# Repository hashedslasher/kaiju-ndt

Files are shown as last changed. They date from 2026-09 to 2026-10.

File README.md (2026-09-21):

# Kaiju U-NDT

This is my team's EE senior design project. It is in very early development and will evolve into an autonomous immersion UT device.
The [pic0rick](https://github.com/kelu124/pic0rick) is used for the pulser/receiver, and the V1 Engineering [MPCNC](https://docs.v1e.com/mpcnc/intro) will be used for xyz gantry

The name Kaiju came from a toy that randomly appeared in our lab one day

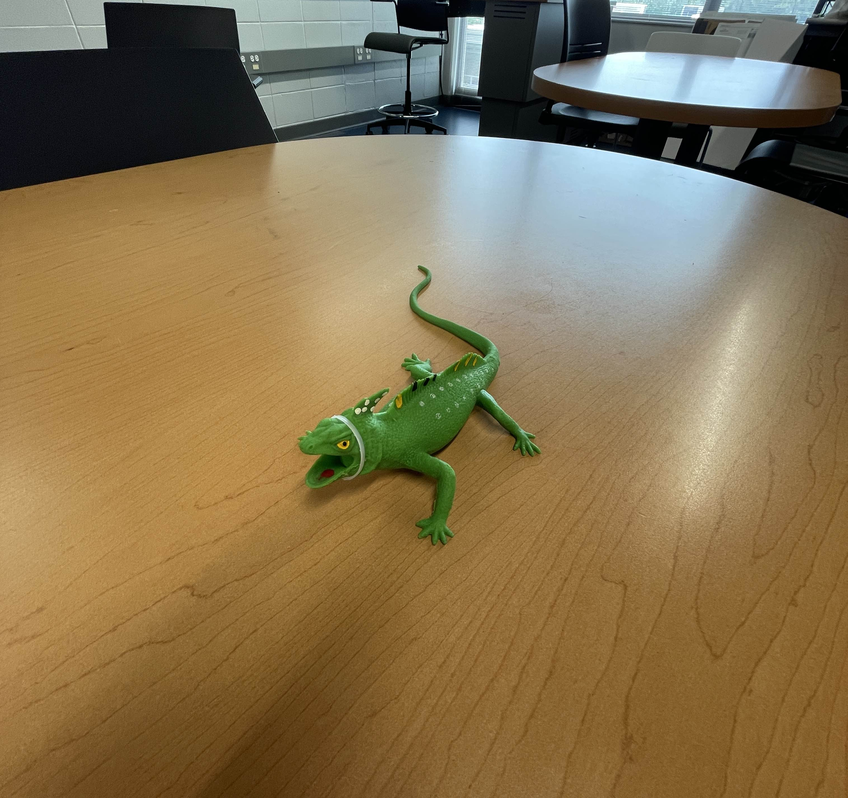
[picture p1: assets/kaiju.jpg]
Kaiju toy


## Development
   If you are working on this project see [Setup](setup/README.md)

## To run the python scripts

1. **Clone the repo**
   Clone the repo (or download as zip) and cd into kaiju-ndt.

2. **Install Python and dependencies**
   - **Windows:** Download from [python.org](https://www.python.org/downloads/windows/) or run:
     ```bash
     winget install -e --id python.python.3.14
     ```
   - **MacOS:** Download from [python.org](https://www.python.org/downloads/macos/) or run:
     ```bash
     brew install python3
     ```
   - **Linux:** Install python with your package manager:
   
   Debian based:
   ```bash
   sudo apt install python3 python3-pip
   ```
   Arch:
   ```bash
   sudo pacman -S python python-pip
   ```
### Python dependencies
   - Open PowerShell or Terminal and run:
     ```bash
     pip install -r python-tools/requirements.txt
     ```

3. **Flashing the firmware**
   - If the firmware isn't already on the pico, you need to flash it.
   - Hold `BOOTSEL` and plug the board in. It should appear as `RPI-RP2`.
   - Drag and drop `firmware/pico/rp2040.uf2` (Pico) or `firmware/pico/rp2350.uf2` (Pico 2) into the `RPI-RP2` drive.
   - Or with picotool from the root of the repository:
   ```bash
   picotool load firmware/pico/rp2040.uf2
   ```

4. **Run a script**
   In PowerShell or Terminal:
   ```bash
   python3 python-tools/{script_name}.py
   ```

   If you use nix for some reason just:
   ```bash
   nix develop .
   python3 python-tools/{script_name}.py
   ```

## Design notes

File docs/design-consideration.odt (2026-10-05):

Design Considerations

Initial Design Considerations

Create an Ultrasonic Testing instrument.

Constraint 1 – Budget

Team agreed to spend $80 per student. 5 students in our team: 5 * $80 = $400.

Team budget: ~$400

Design consideration modified - 1

Create an affordable Ultrasonic Testing instrument based on a pre existing AFE.

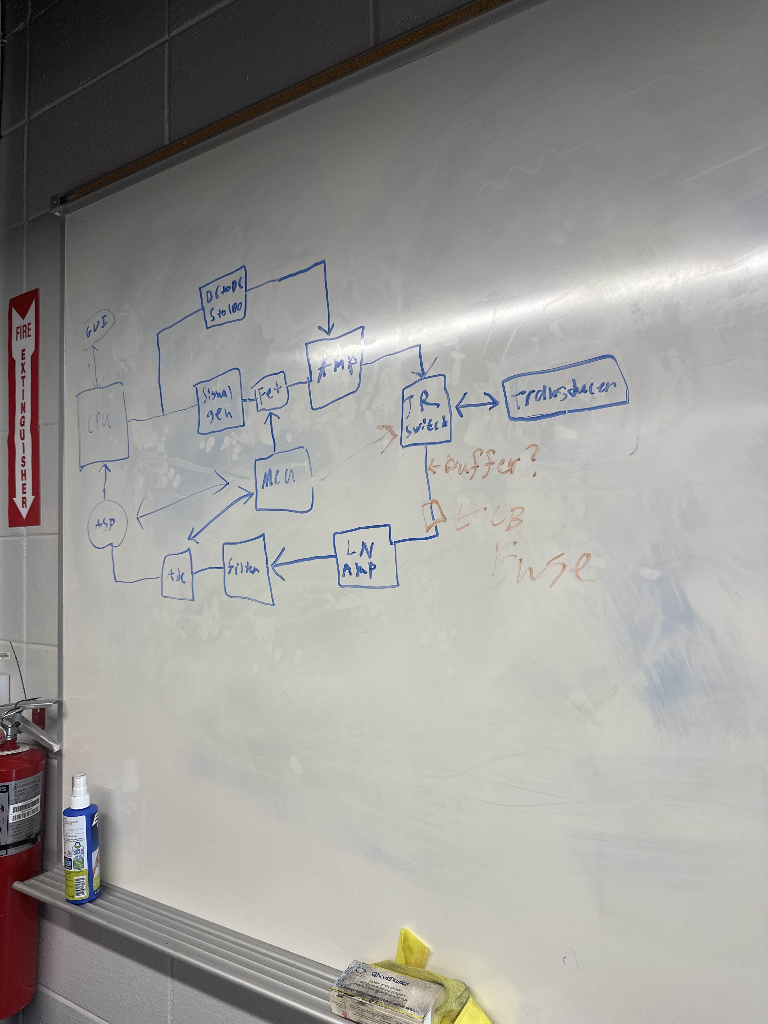
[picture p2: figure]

Basic block diagram of a pulse-echo system using tone burst (Layton).

Visted Marietta NDT. Advised to use an existing instrument and work at the system level. Potentially receiving an immersion probe.

Design consideration modified – 2 (Final)

Affordable Autonomous immersion defect detection system capable of producing C-scans.

Instrument Investigation

Discovered Echomods project: Family of open-source ultrasound pulser/reciever boards - (Layton)

Instruments considered (technically, these are pulser/reciever boards):

Board | Capabilities
lit3-32 | Capable of 100V 3 line pwm pulses. Controlled by FPGA (iCE40). 92dB gain VGA
un0rick | Capable of 25V, 50V, or 75V pwm pulses. Controlled by FPGA (iCE40). 48dB VGA
pic0rick | Capable of +-25V 3 line pwm pulses. Controlled by RP2040/RP2350. 48dB VGA

lit3-32 and un0rick are legacy and no longer produced. Pic0rick is the only modern option in it’s class and price range.

Due to the entire echomods project being open-source, printing the lit3-32 was strongly considered but advised against by senior project professor.

Pic0rick and lit3-32 were around the same price. After considering common probe specs, Pic0rick can achieve desired results, but overhead of lit3-32 and FPGA flexabilty would provide better results.

Pic0rick was selected with raspberry pi pico as MCU - (Layton).

Budget Update

Board and acessories (headers, sma connectors, sma cables, pico) totaled to ~$400. Board and accessories were purchased with financial assistance from senior project professor.

New team buget: $400 + $400 - $400 = $400

Design Constraint - 2

Raspberry pi pico uses USB 1.1, theoretically 12Mbps, practically much lower.

Design Constraint - 3

Pic0rick board leaves 8 remaining gpio pins. Need to eventually drive motors (limit switches, E-stop, temp sensors).

Initial Testing

Main board (reciever) and daughter board (pulser) arrived. Headers and Raspberry pi pico 1 were installed (Harrison). Board was hooked up to 10Mhz delay-line contact probe provided by senior project professor. Extremely minimal firmware gave a completely raw, one-pulse signal with no DSP. Pulse was called with simple python function through live python environment with computer connected to board via serial (usb).

Signal filtering was then applied (through interface) via bandpass filter, averaging, and hilbert envelop and displayed with pyqt. Target was a blank slab of steel with no known defects. Patroleum jelly was used as couplant.

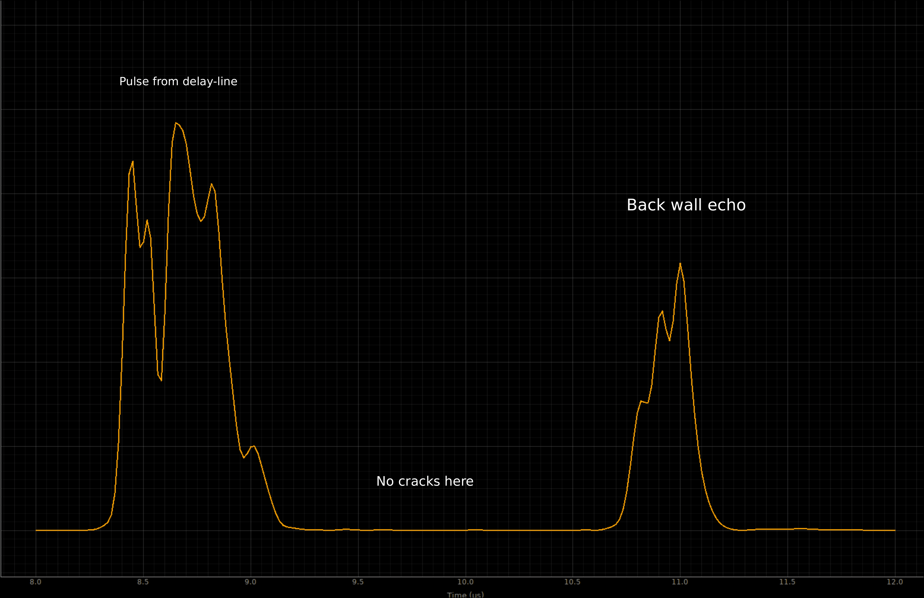
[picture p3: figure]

Python script was implemented to loop python function that triggers pulse and acquisition, along with windowing feature, input for gain, etc. (Mathew). Acquisition rate was approximately 1 pulse per 2 seconds.

Firmware was overhauled to use fast_pico_serial (Layton). Acquisition rate jumped to approximately 30 pulses per second with above signal processing and 2 signal averages.

Motion System Considerations

Used 3D printers and frugal CNC machines were considered for xyz motion system. Most 3D printers at a reasonable price move bed for y movement. This is not acceptable as water in scan area is sloshed. Both consumer/commercial CNC machines and 3D printers use dedicated microcontrollers with propriatary, unmodifiable firmware.

The MPCNC (Mostly Printable CNC) was discovered – (Layton)

The MPCNC is a guide to build a CNC machine with 3D printed parts and items found at local hardware stores and movement is driven by user choice of 5 Nema-17 motors. The user is required to choose microcontroller and motor drivers.

MPCNC was selected – (Layton)

Original MPCNC qoute for user sourcing parts was ~$450 (including cnc router, which isn’t used here)

MPCNC parts were reviewed for practicality and printed (Layton, Harrison, Matthew)

MPCNC was successfully assembled (Mathew) for ~$280

MCU Considerations

To get a usable scan resolution, micro controller needs to either support much higher serial transfer rate, or allow for onboard dsp to shrink size of data sent over serial.

Motors can be driven by the 8 remaining gpio pins due to 2 x axis motors rotating in opposing direction and 2 y axis motors rotating in opposing direction. This leaves no room for limit switches, E-stop, etc.

Solution | Pros | cons
PCB with motor controllers built around teensy 4.0. M/s setup between teensy and pico 1 | 3.0 USB speeds. Heavier onboard DSP. more gpio | Cost of teensy 4.0. M/s complexity. 2 sets of firmware
Move pic0rick to pico 2. Build gpio extension/motor driver drop in PCB | Onboard DSP with arm_math (none on pico 1). $2 increase in MCU cost. | Still limited to usb 1.1. added complexity of gpio expansion PCB

Replace pico 1 with pico 2 on pic0rick. Build gpio expansion pcb - (Layton)

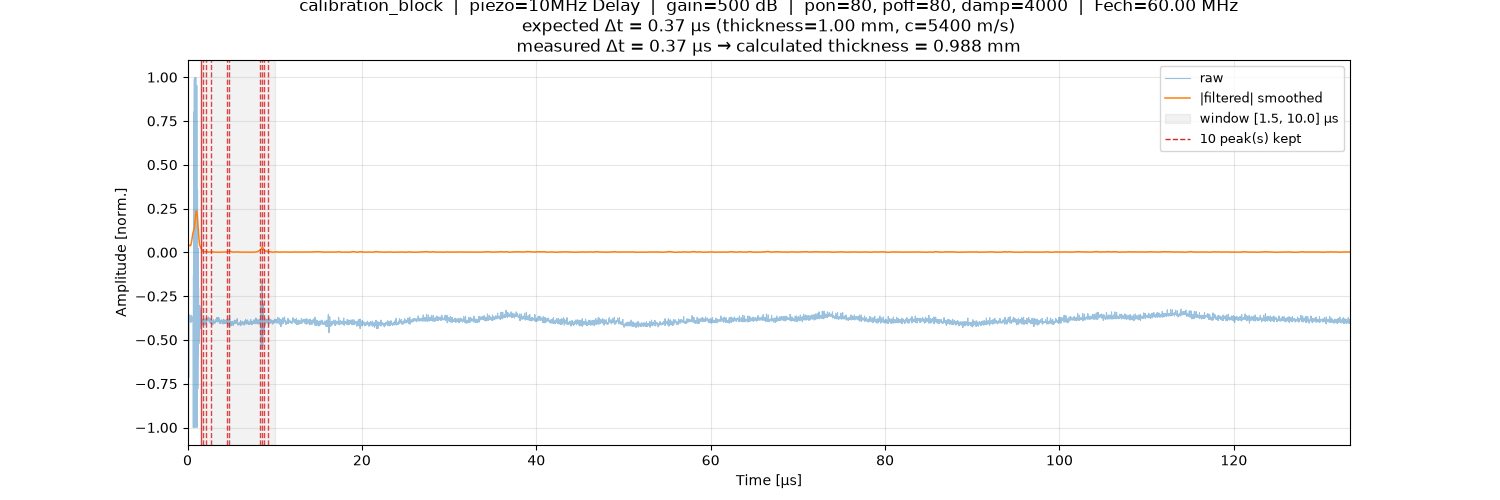
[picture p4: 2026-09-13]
plots/9-4-26/plot_20260904_140533.png

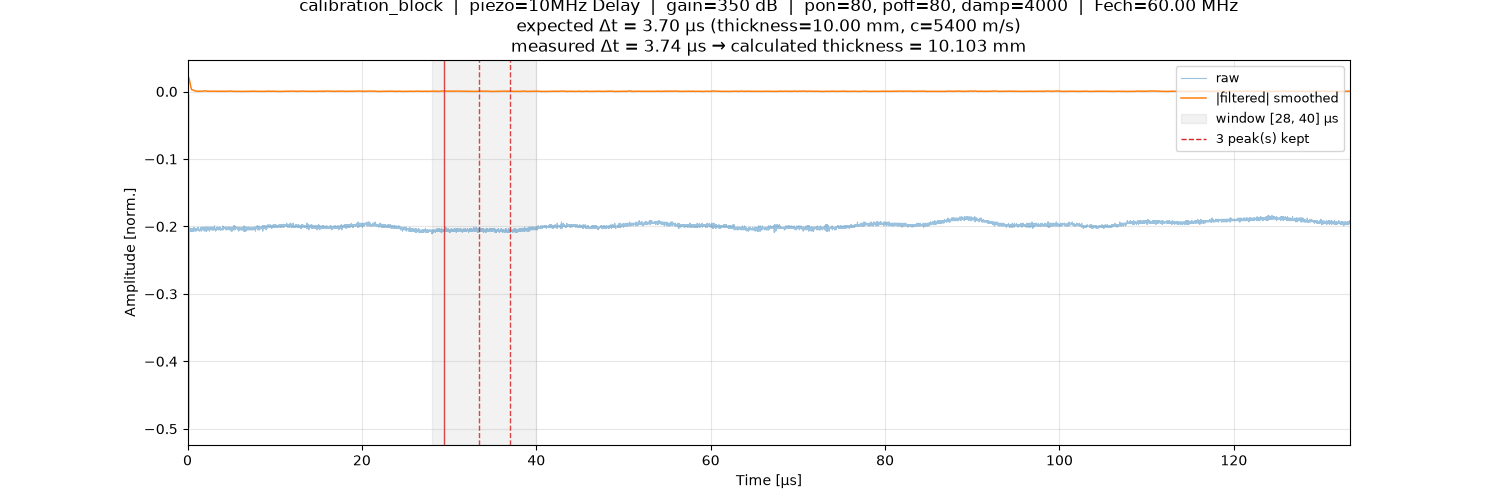
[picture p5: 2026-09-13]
plots/9-4-26/plot_20260904_145508.png

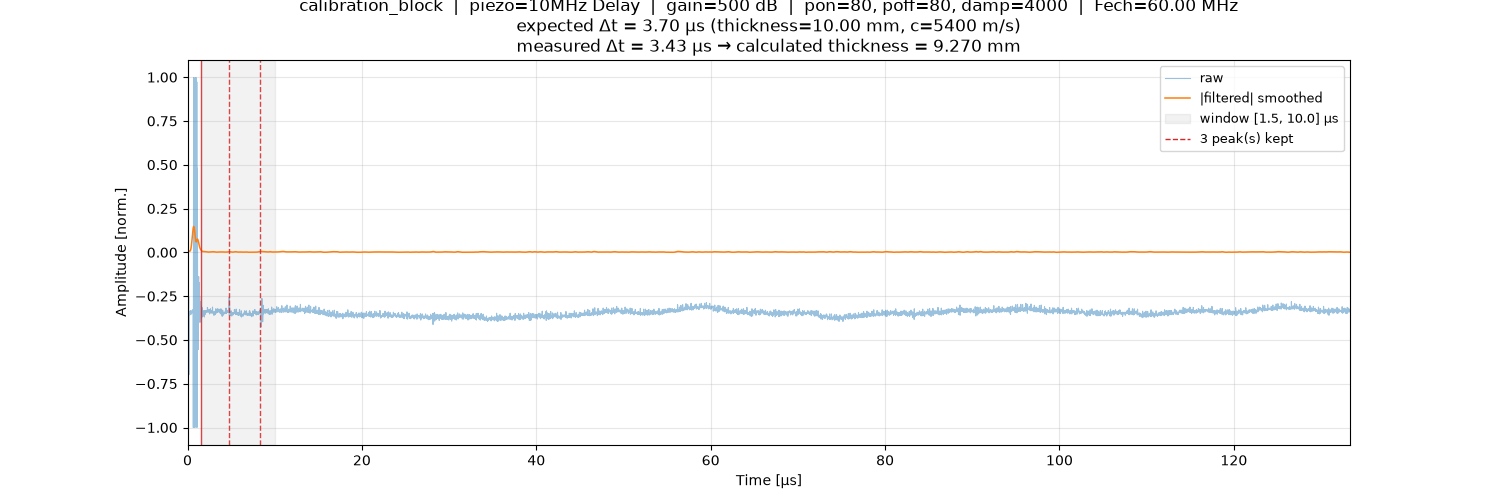
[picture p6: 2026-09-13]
plots/9-4-26/plot_20260904_141416.png

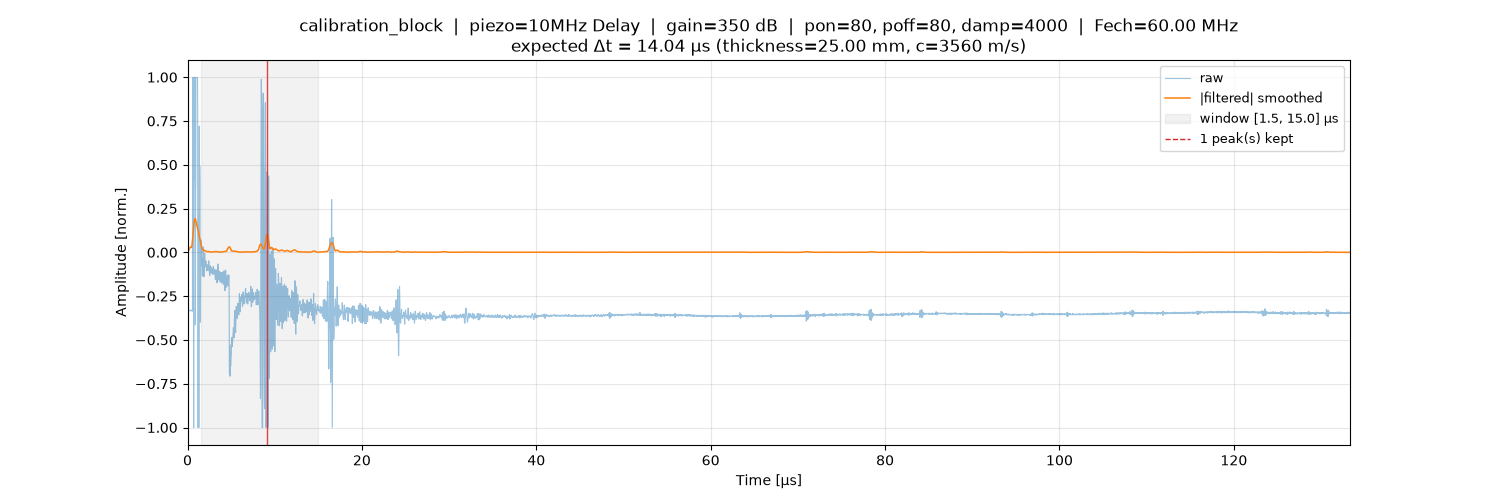
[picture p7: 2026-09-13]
plots/9-3-26/plot_20260903_191736.png

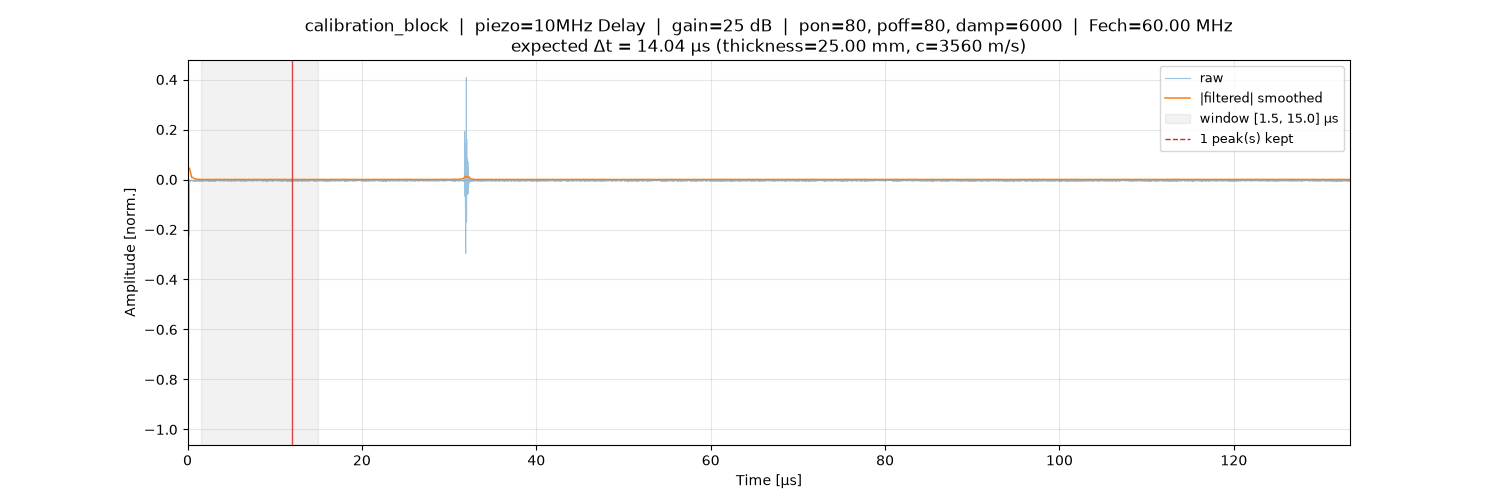
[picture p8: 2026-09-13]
plots/9-3-26/plot_20260903_185810.png

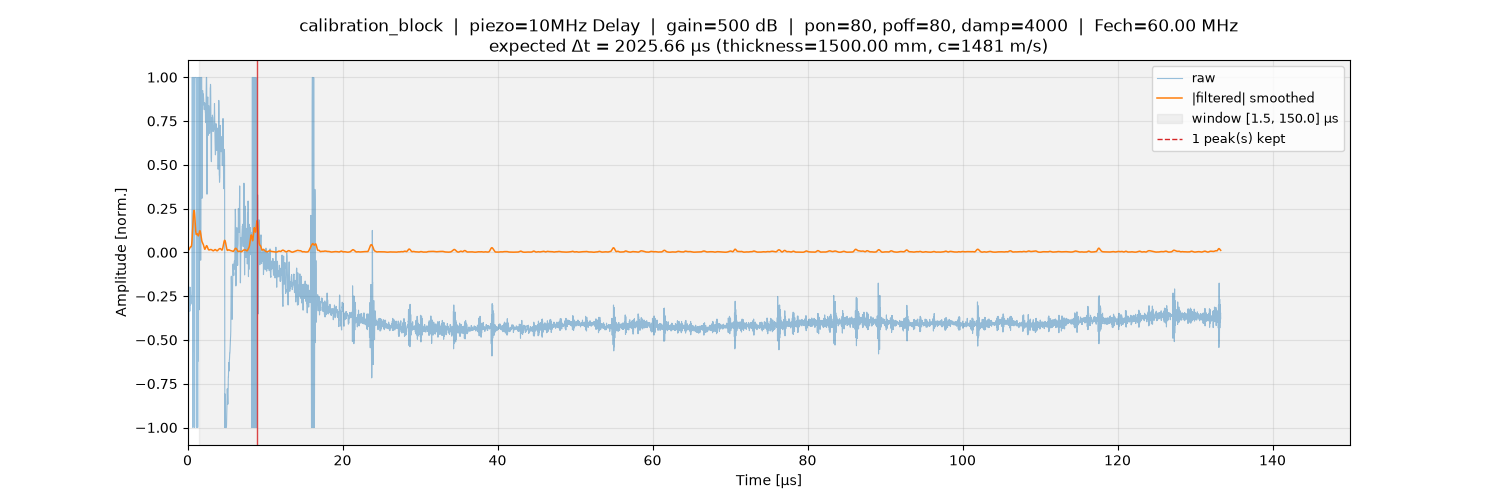
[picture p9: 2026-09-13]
plots/9-4-26/plot_20260904_101338.png

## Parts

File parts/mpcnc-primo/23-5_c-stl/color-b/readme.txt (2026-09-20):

45% infill - I would print multiple at a time if you can

corner-bottom: 2
corner-bottom-mirrored: 2
upper-belt: 2
upper-belt-mirrored: 2
corner-leg-lock: 4
truck-clamp: 4

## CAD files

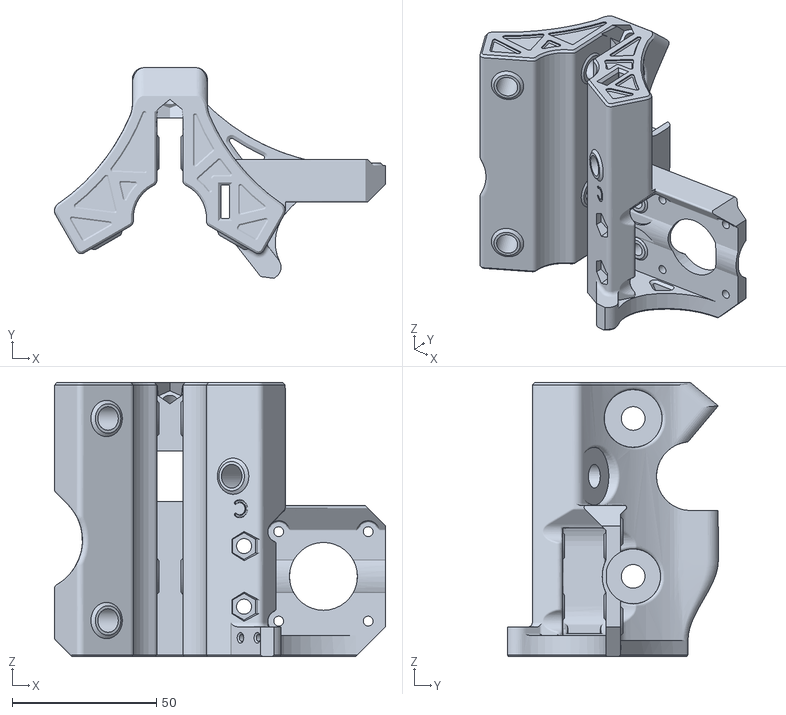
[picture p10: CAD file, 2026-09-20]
parts/mpcnc-primo/23-5_c-stl/color-a/truck-mirrored-no-logo.stl
114.7 x 73.0 x 95.0

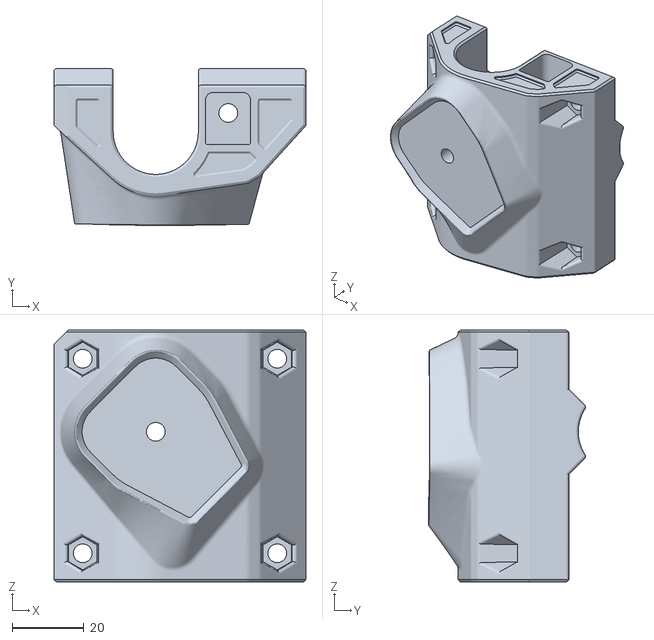
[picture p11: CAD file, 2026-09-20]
parts/mpcnc-primo/23-5_c-stl/color-b/corner-bottom-mirrored-no-logo.stl
70.2 x 43.8 x 70.2

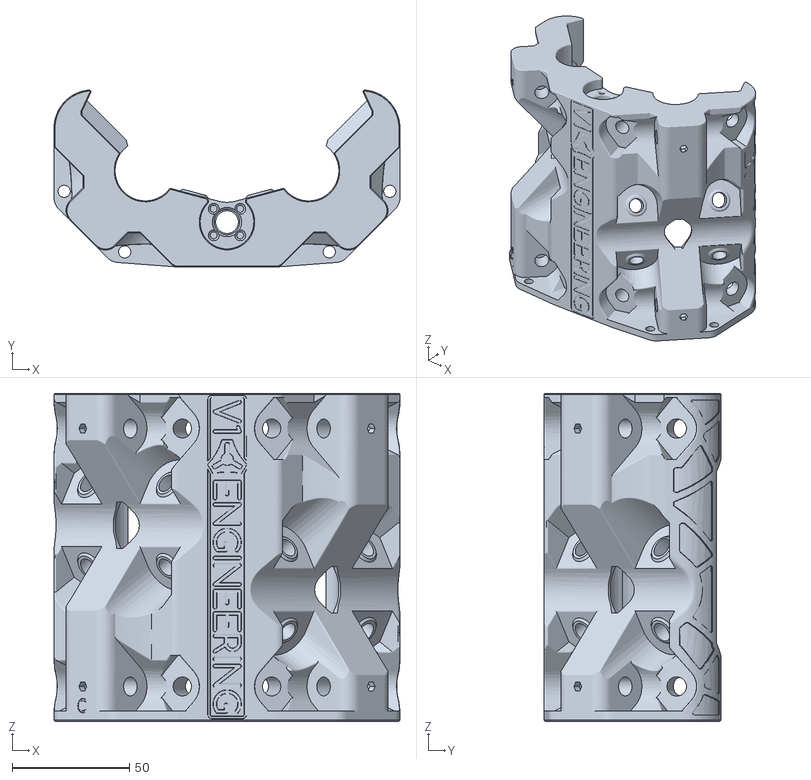
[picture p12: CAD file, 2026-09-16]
parts/mpcnc-primo/core-c-primo.stl
147.6 x 75.5 x 140.0

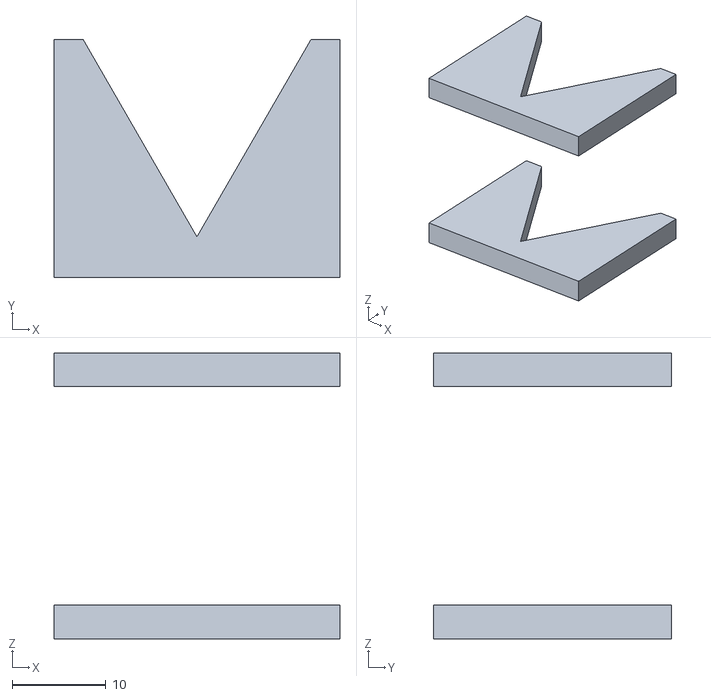
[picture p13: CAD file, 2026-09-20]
parts/tri-prism-holder.STL
30.5 x 25.4 x 30.5

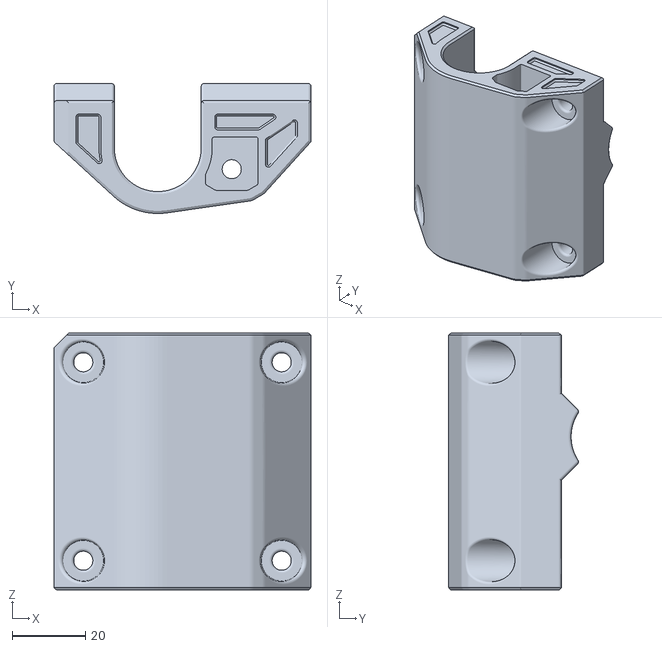
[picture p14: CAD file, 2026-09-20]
parts/mpcnc-primo/23-5_c-stl/color-a/corner-top-mirrored-no-logo.stl
70.2 x 35.5 x 70.2

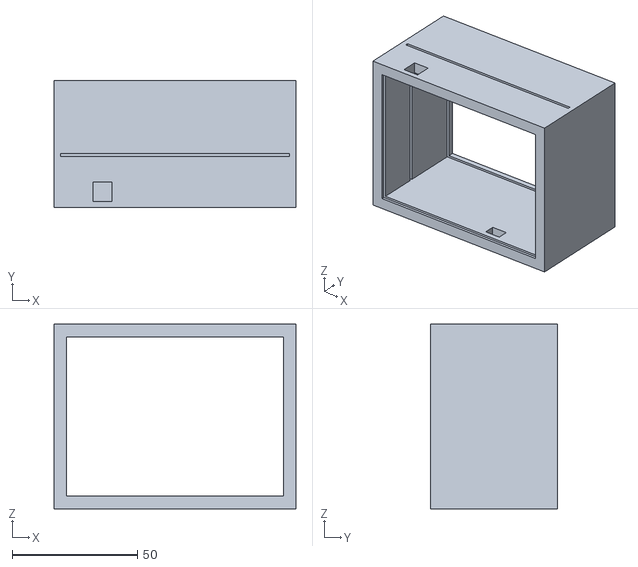
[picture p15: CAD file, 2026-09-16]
parts/pickle-jar_v1.STL
96.6 x 50.8 x 73.7

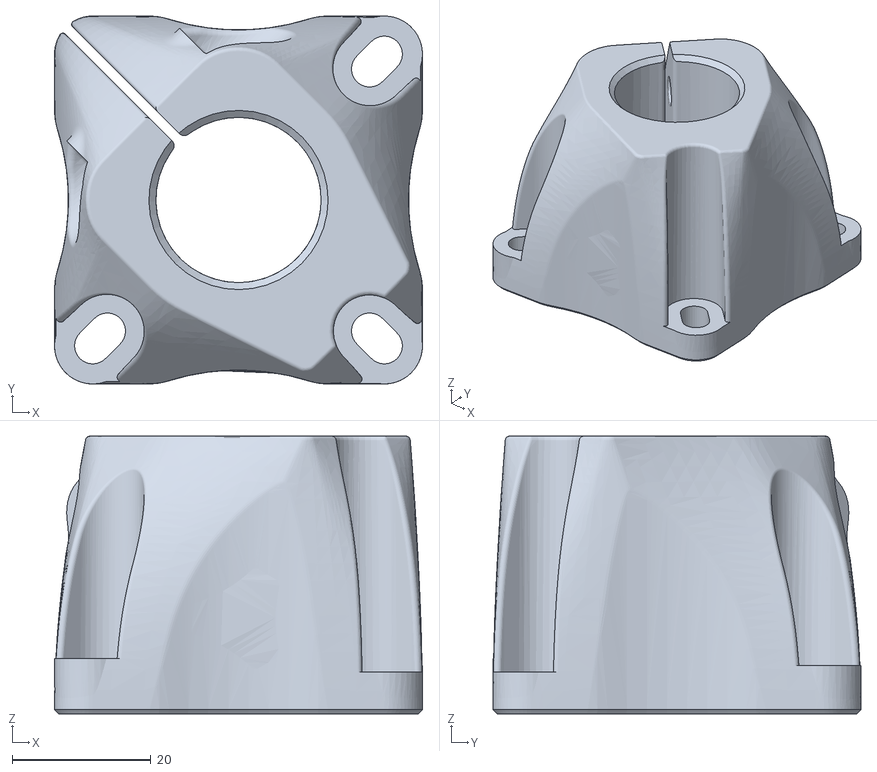
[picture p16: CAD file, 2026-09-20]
parts/mpcnc-primo/23-5_c-stl/color-a/feet-no-logo.stl
53.0 x 53.0 x 40.0

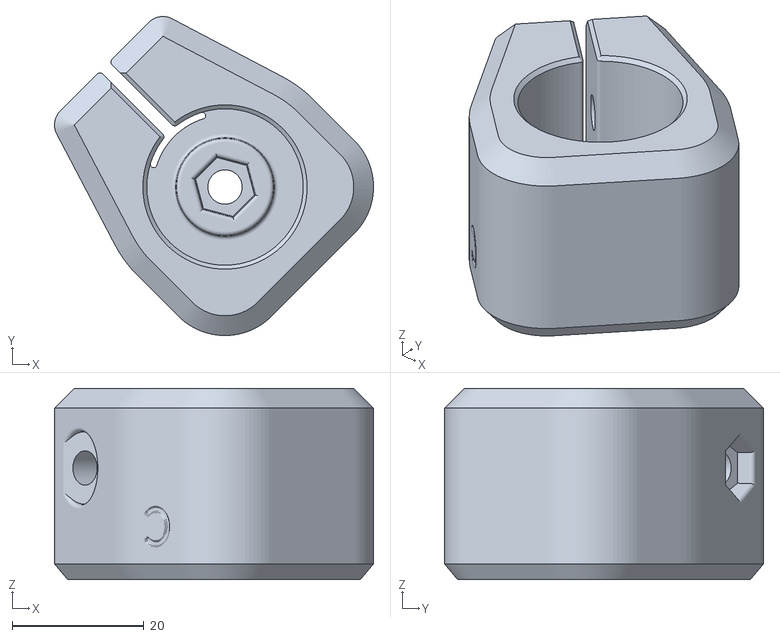
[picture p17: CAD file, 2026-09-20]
parts/mpcnc-primo/23-5_c-stl/color-b/corner-leg-lock-no-logo.stl
48.4 x 48.4 x 29.0

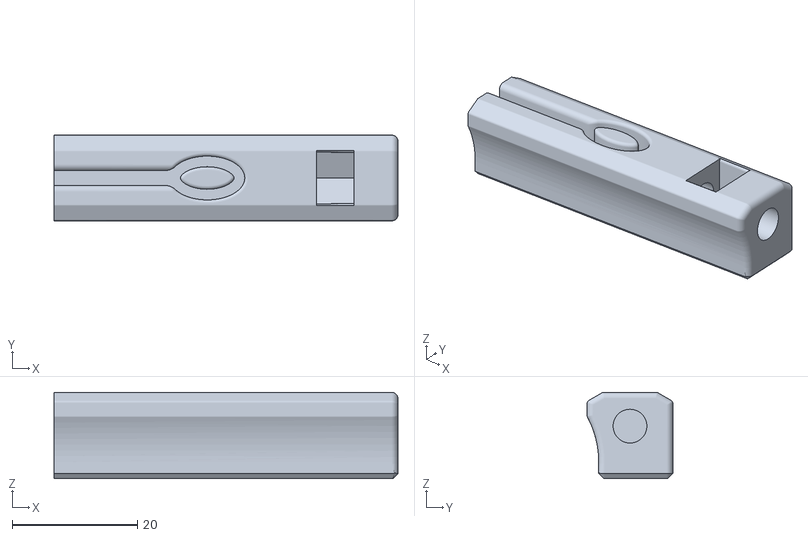
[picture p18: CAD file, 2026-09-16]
parts/mpcnc-primo/23-5_c-stl/color-b/upper-belt-mirrored.stl
55.0 x 13.7 x 13.8

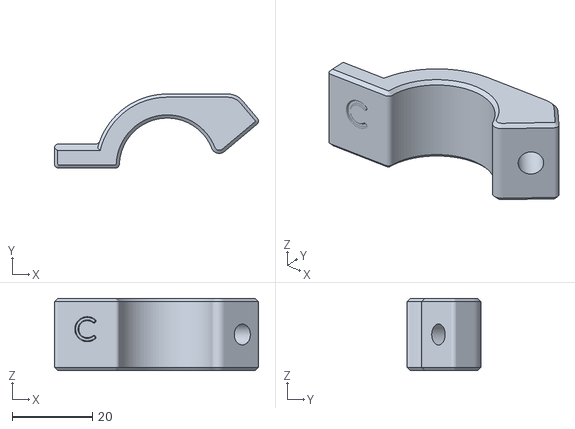
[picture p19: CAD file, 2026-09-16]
parts/mpcnc-primo/23-5_c-stl/color-b/truck-clamp.STL
50.7 x 18.4 x 18.0

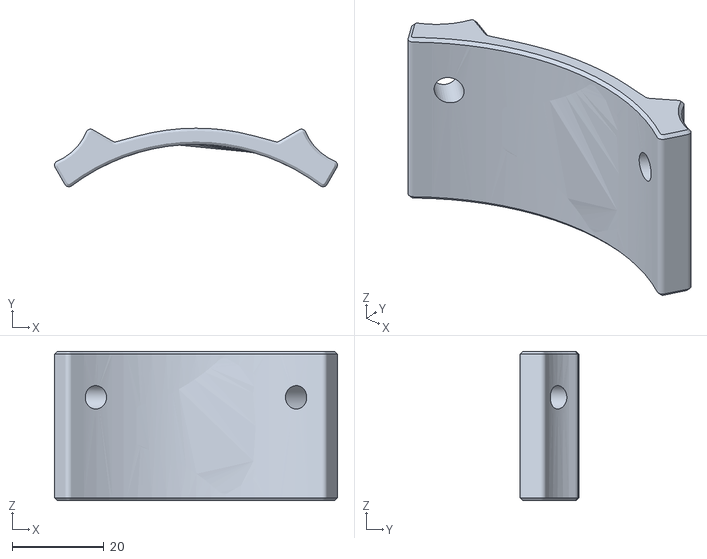
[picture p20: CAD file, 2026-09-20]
parts/mpcnc-primo/23-5_c-stl/color-a/lower-tool-plate-no-logo.stl
61.7 x 12.8 x 32.5

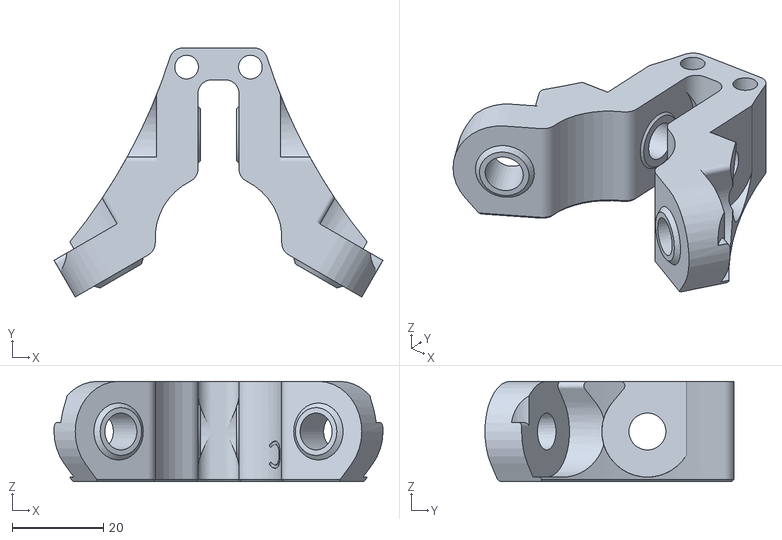
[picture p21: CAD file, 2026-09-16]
parts/mpcnc-primo/23-5_c-stl/color-a/core-clamp.STL
72.2 x 54.7 x 22.0

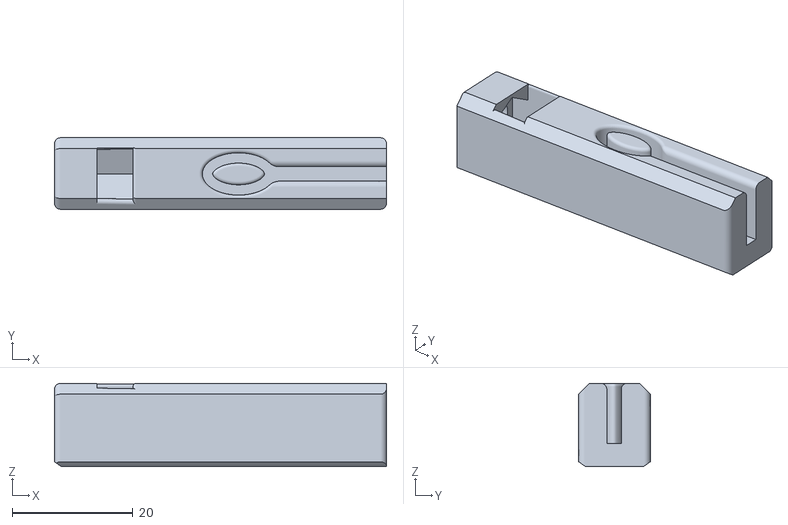
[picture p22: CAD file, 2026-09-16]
parts/mpcnc-primo/23-5_c-stl/color-a/lower-belt.STL
55.0 x 11.8 x 13.8

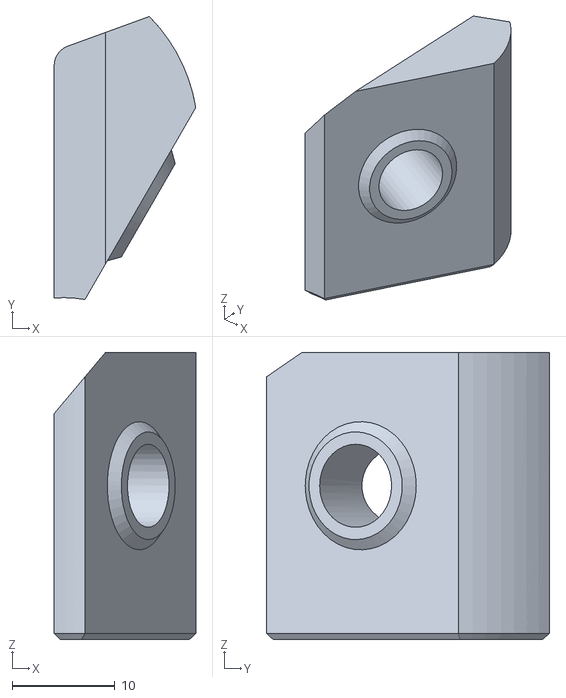
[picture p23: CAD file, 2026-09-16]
parts/mpcnc-primo/23-5_c-stl/color-a/core-z-clamp-1.STL
13.8 x 27.6 x 28.0

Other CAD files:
parts/mpcnc-primo/23-5_c-stl/color-b/croner-bottom-no-logo.stl
parts/mpcnc-primo/23-5_c-stl/color-a/corner-top-no-logo.stl
parts/mpcnc-primo/23-5_c-stl/color-b/upper-belt.STL
parts/mpcnc-primo/23-5_c-stl/color-a/truck-no-logo.stl
parts/mpcnc-primo/23-5_c-stl/color-a/core-clamp-y.STL
parts/mpcnc-primo/23-5_c-stl/color-a/core-z-clamp-2.STL
parts/mpcnc-primo/23-5_c-stl/color-a/lower-belt-mirrored.stl
parts/mpcnc-primo/23-5_c-stl/color-a/nut-trap-no-logo.stl
parts/mpcnc-primo/23-5_c-stl/color-a/stop-block.STL
parts/mpcnc-primo/23-5_c-stl/color-a/upper-tool-plate.STL
parts/mpcnc-primo/23-5_c-stl/color-a/wire-darryl.STL
parts/mpcnc-primo/23-5_c-stl/color-a/z-coupler.STL
parts/mpcnc-primo/23-5_c-stl/color-a/z-motor.STL

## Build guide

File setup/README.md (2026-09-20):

# Development setup and building

## Setup
  
  Clone the repository if you already have git installed, or download as a zip from the front page
  
  ### Windows
  1. Open powershell and navigate to kaiju-ndt/setup
    
  2. Then run:
      ```bash
      .\setup-windows.ps1
      ```
  3. Install [qt5](https://www.qt.io/development/download-qt-installer-oss)
  
  ### Linux
  1. Open a terminal and navigate to kaiju-ndt/setup
    
  2. Then run:
      ```bash
      chmod +x setup-linux.sh;./setup-linux.sh
      ```

## Building pico firmware and the c++ acquisition app
  Navigate to app or firmware/pico, depending on what you want to build.

  ### Windows
  ```bash
  .\build.ps1
  ```
  ### Linux
  ```bash
  ./build.sh
  ```
  To run the acquisition app after building open your file explorer navigate to kaiju-ndt/app/build, click on kaiju-ndt

  See [Home](../README.md) to flash pico firmware

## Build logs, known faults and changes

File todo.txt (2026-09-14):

write app/src/device.cpp

helpers for current python test scripts (gui input for material, etc.)

onboard dsp

standards:

22232-1 - Non-destructive testing — Characterization and verification of ultrasonic test equipment. Part-1: Instruments
22232-2 - Non-destructive testing — Characterization and verification of ultrasonic test equipment. Part-2: Probes
22232-3 - Non-destructive testing — Characterization and verification of ultrasonic test equipment. Part 3: Combined equipment
ASTM E1065 - Standard Practice for Evaluating Characteristics of Ultrasonic Search Units
ASTM E164 - Standard Practice for Contact Ultrasonic Testing of Weldments
ASTM E1001-11 - Standard Practice for Detection and Evaluation of Discontinuities by the Immersed Pulse-Echo Ultrasonic Method Using Longitudinal Waves

Ask Ryan for these documents, say we wan't to "characterize probe/instrument"

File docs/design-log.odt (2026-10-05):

ID | Category | Considered | Decision | Reason | Date
D-001 | Instrument | Lit-3-32, un0rick, Pic0rick | Pic0rick | Cost, availability, simplicity | 8/18/26
D-002 | Motion System | 3D printer, Consumer CNC, MPCNC | MPCNC | Wide range of configurability | 9/8/26
D-003 | Controller | Teensy 4.0 with M/s, pico 2 | Pico 2 | Simplicity, cost | 9/17/26
D-004

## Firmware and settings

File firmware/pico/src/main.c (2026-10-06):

//---------------------------------------------------------------------------
// INCLUDES
//--------------------------------------------------------------------------
#include "adc/adc.h"
#include "max/max14866.h"
#include "motors/motors.h"
#include "../external/pico_fast_serial/fast_serial.h"

//---------------------------------------------------------------------------
// GLOBALS
//--------------------------------------------------------------------------

typedef void (*command_func_t)(const char *args);

typedef struct
{
    const char *command_name;
    command_func_t func;
} command_t;

command_t command_list[] = {
    {"start acq", pulse_adc_trigger},
    {"write dac", dac},
    {"write mux", max14866},
    {"set mux", max14866_set},
    {"clear mux", max14866_clear},
    {"read", adc},
    {"move x", move_x},
    {"move y", move_y},
    {"move z", move_z},
};

void process_command(char *input)
{
    char *command = strtok(input, " \r\n");
    char *subcommand = strtok(NULL, " \r\n");
    char *args = strtok(NULL, "\r\n");
    
    if (command != NULL && subcommand != NULL)
    {
        char full_command[50];
        snprintf(full_command, sizeof(full_command), "%s %s", command, subcommand);

        for (int i = 0; i < sizeof(command_list) / sizeof(command_t); i++)
        {
            if (strcmp(full_command, command_list[i].command_name) == 0)
            {
                if (args == NULL)
                {
                    args = "0";
                }
                command_list[i].func(args);
                return;
            }
        }
        printf("Unknown command: %s %s\n", command, subcommand);
    }
    else if (command != NULL)
    {
        for (int i = 0; i < sizeof(command_list) / sizeof(command_t); i++)
        {
            if (strcmp(command, command_list[i].command_name) == 0)
            {
                command_list[i].func(args);
                return;
            }
        }
        printf("Unknown command: %s\n", command);
    }
}

void read_input(char *buffer, int max_len)
{
    int len = fast_serial_read_until(buffer, max_len, '\n'); 
    
    if (len > 0) {
        buffer[len] = '\0';
        if (buffer[len - 1] == '\r') {
            buffer[len - 1] = '\0';
        }
    } else {
        buffer[0] = '\0';
    }
}


//---------------------------------------------------------------------------
// MAIN FUNCTION
//---------------------------------------------------------------------------

int main()
{
    fast_serial_init();
    while (!tud_mounted())
    {
        tud_task();
        tight_loop_contents();
    }
    
    sleep_ms(100);
    pio_adc_init();
    sleep_ms(100);
    dac_init();
    sleep_ms(100);
    max14866_init();
    sleep_ms(100);
    motor_setup();

    char input[128];
    while (true)
    {
        fast_serial_task();
        
        
        read_input(input, sizeof(input));
        if (input[0] != '\0')
        {
            process_command(input);
        }
    }
}

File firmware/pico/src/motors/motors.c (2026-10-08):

#include "pico/stdlib.h"
#include "hardware/pio.h"
#include "hardware/dma.h"
#include "hardware/clocks.h"
#include "string.h"
#include "stdio.h"
#include "motors.pio.h"

#define STEP_PIN_X  18
#define DIR_PIN_X   19
#define STEP_PIN_Y  20
#define DIR_PIN_Y   21
#define STEP_PIN_Z  22
#define DIR_PIN_Z   26
#define EN_PIN      28

#define MAX_STEPS       5000 
#define START_FREQ_HZ   100
#define MAX_RAMP_STEPS  100

uint32_t step_profile_x[MAX_STEPS];
uint32_t step_profile_y[MAX_STEPS];
uint32_t step_profile_z[MAX_STEPS];

int dma_chan_x = -1;
int dma_chan_y = -1;
int dma_chan_z = -1;

PIO motor_pio = pio0;
uint motor_pio_offset;

void init_motor_sm(PIO pio, uint sm, uint offset, uint step_pin, uint dir_pin) {
    pio_gpio_init(pio, step_pin);
    pio_gpio_init(pio, dir_pin);
    pio_sm_set_consecutive_pindirs(pio, sm, step_pin, 1, true);
    pio_sm_set_consecutive_pindirs(pio, sm, dir_pin, 1, true);

    pio_sm_config c = stepper_ctrl_program_get_default_config(offset);
    sm_config_set_set_pins(&c, step_pin, 1);
    sm_config_set_sideset_pins(&c, dir_pin); 
    
    pio_sm_init(pio, sm, offset, &c);
    pio_sm_set_enabled(pio, sm, true);
}

void start_dma(PIO pio, uint sm, int dma_chan, uint32_t* profile, uint32_t steps) {
    if (dma_channel_is_busy(dma_chan)) {
        dma_channel_abort(dma_chan);
        pio_sm_clear_fifos(pio, sm);
    }

    dma_channel_config c = dma_channel_get_default_config(dma_chan);
    channel_config_set_transfer_data_size(&c, DMA_SIZE_32);
    channel_config_set_read_increment(&c, true);
    channel_config_set_write_increment(&c, false);
    channel_config_set_dreq(&c, pio_get_dreq(pio, sm, true));

    dma_channel_configure(
        dma_chan, &c,
        &pio->txf[sm], 
        profile,       
        steps,
        true           
    );
}

void motor_setup() {
    gpio_init(EN_PIN);
    gpio_set_dir(EN_PIN, GPIO_OUT);
    gpio_put(EN_PIN, 0); 

    motor_pio_offset = pio_add_program(motor_pio, &stepper_ctrl_program);

    init_motor_sm(motor_pio, 0, motor_pio_offset, STEP_PIN_X, DIR_PIN_X);
    init_motor_sm(motor_pio, 1, motor_pio_offset, STEP_PIN_Y, DIR_PIN_Y);
    init_motor_sm(motor_pio, 2, motor_pio_offset, STEP_PIN_Z, DIR_PIN_Z);

    dma_chan_x = dma_claim_unused_channel(true);
    dma_chan_y = dma_claim_unused_channel(true);
    dma_chan_z = dma_claim_unused_channel(true);
}

void ramp_profile(uint32_t* profile_array, bool dir_bit, uint32_t target_freq_hz, uint32_t steps) {
    uint32_t sys_clk = clock_get_hz(clk_sys);
    uint32_t start_freq = START_FREQ_HZ;
    uint32_t ramp_steps = MAX_RAMP_STEPS;
    
    if (steps < (MAX_RAMP_STEPS * 2)) {
        ramp_steps = steps / 2;
    }

    if (target_freq_hz <= start_freq) {
        start_freq = target_freq_hz;
        ramp_steps = 0;
    }

    float freq_inc = 0;
    if (ramp_steps > 0) {
        freq_inc = (float)(target_freq_hz - start_freq) / ramp_steps;
    }

    for (uint32_t i = 0; i < steps; i++) {
        uint32_t current_freq = target_freq_hz;

        if (i < ramp_steps) {
            current_freq = start_freq + (uint32_t)(i * freq_inc);
        } else if (i >= steps - ramp_steps) {
            uint32_t decel_step = steps - i; 
            current_freq = start_freq + (uint32_t)(decel_step * freq_inc);
        }

        uint32_t delay = (sys_clk / current_freq) - 32;
        profile_array[i] = (dir_bit ? 0x80000000 : 0) | (delay & 0x7FFFFFFF);
    }
}

void move_x(const char *args) {
    char dir_str[16];
    uint32_t freq_hz = 0;
    uint32_t steps = 0;

    if (sscanf(args, "%15s %lu %lu", dir_str, &freq_hz, &steps) != 3) {
        return;
    }

    if (steps > MAX_STEPS) steps = MAX_STEPS;
    if (steps == 0 || freq_hz == 0) return;

    bool dir_bit = false;
    if (strcmp(dir_str, "plus") == 0) dir_bit = true;
    else if (strcmp(dir_str, "minus") == 0) dir_bit = false;
    else return;

    ramp_profile(step_profile_x, dir_bit, freq_hz, steps);
    start_dma(motor_pio, 0, dma_chan_x, step_profile_x, steps);
}

void move_y(const char *args) {
    char dir_str[16];
    uint32_t freq_hz = 0;
    uint32_t steps = 0;

    if (sscanf(args, "%15s %lu %lu", dir_str, &freq_hz, &steps) != 3) return;
    if (steps > MAX_STEPS) steps = MAX_STEPS;
    if (steps == 0 || freq_hz == 0) return;

    bool dir_bit = false;
    if (strcmp(dir_str, "plus") == 0) dir_bit = true;
    else if (strcmp(dir_str, "minus") == 0) dir_bit = false;
    else return;

    ramp_profile(step_profile_y, dir_bit, freq_hz, steps);
    start_dma(motor_pio, 1, dma_chan_y, step_profile_y, steps);
}

void move_z(const char *args) {
    char dir_str[16];
    uint32_t freq_hz = 0;
    uint32_t steps = 0;

    if (sscanf(args, "%15s %lu %lu", dir_str, &freq_hz, &steps) != 3) return;
    if (steps > MAX_STEPS) steps = MAX_STEPS;
    if (steps == 0 || freq_hz == 0) return;

    bool dir_bit = false;
    if (strcmp(dir_str, "plus") == 0 || strcmp(dir_str, "up") == 0) dir_bit = true;
    else if (strcmp(dir_str, "minus") == 0 || strcmp(dir_str, "down") == 0) dir_bit = false;
    else return;

    ramp_profile(step_profile_z, dir_bit, freq_hz, steps);
    start_dma(motor_pio, 2, dma_chan_z, step_profile_z, steps);
}

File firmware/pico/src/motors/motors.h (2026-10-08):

#ifndef MOTORS_H
#define MOTORS_H

#ifdef __cplusplus
extern "C" {
#endif

#include <stdint.h>
#include <stdbool.h>
#include "pico/stdlib.h"
#include "hardware/pio.h"

#define STEP_PIN_X  18
#define DIR_PIN_X   19
#define STEP_PIN_Y  20
#define DIR_PIN_Y   21
#define STEP_PIN_Z  22
#define DIR_PIN_Z   26
#define EN_PIN      28

#define MAX_STEPS       5000 
#define START_FREQ_HZ   100
#define MAX_RAMP_STEPS  100

extern uint32_t step_profile_x[MAX_STEPS];
extern uint32_t step_profile_y[MAX_STEPS];
extern uint32_t step_profile_z[MAX_STEPS];

extern int dma_chan_x;
extern int dma_chan_y;
extern int dma_chan_z;

extern PIO motor_pio;
extern uint motor_pio_offset;

void motor_setup(void);
void move_x(const char *args);
void move_y(const char *args);
void move_z(const char *args);

void init_motor_sm(PIO pio, uint sm, uint offset, uint step_pin, uint dir_pin);
void start_dma(PIO pio, uint sm, int dma_chan, uint32_t* profile, uint32_t steps);
void ramp_profile(uint32_t* profile_array, bool dir_bit, uint32_t target_freq_hz, uint32_t steps);

#ifdef __cplusplus
}
#endif

#endif // MOTORS_H

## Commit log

2026-09-13 I'm tired
2026-09-16 fixed python device recognition for windows
2026-09-16 3d parts
    [Core C Primo.STL, Core Clamp C Primo.STL, Core Clamp C Y Primo.STL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]
2026-09-17 removed g code
    [Core C Primo.STL, Core Clamp C Primo.STL, Core Clamp C Y Primo.STL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]
2026-09-20 removed logo from parts
    [core-clamp-y.STL, core-clamp.STL, core-with-logo.STL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]
2026-09-20 parts update
    [Core C Primo.STL, Core Clamp C Primo.STL, Core Clamp C Y Primo.STL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]
2026-09-20 removed logo from core
    [core-no-logo.stl]
2026-09-21 core stl fixed
    [core-no-logo.stl]
2026-09-22 backlash stl file and python script
    [antibacklash-bottom-fixture-hex_abs.stl, antibacklash-top-fixture-hex_abs.stl]
2026-10-05 docs and motors
    [Core C Primo No Logo Fixed.stl, antibacklash-bottom-fixture-hex_abs.stl, antibacklash-top-fixture-hex_abs.stl]
2026-10-05 changes to motors.c
2026-10-05 motors.c fix
2026-10-06 fixed keyboard jogging for motors
    [main.c, motors.c, motors.h]
2026-10-08 motors.pio and changes to motors.c
2026-10-12 motors and acq motor fix
2026-10-20 motor positioning and homing
2026-10-23 kaijus daughter board
